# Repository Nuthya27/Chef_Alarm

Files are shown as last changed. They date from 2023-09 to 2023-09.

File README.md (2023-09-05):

# Chef_Alarm

My first individual project, Chef Alarm, the modern precision cooking equipment is made to take culinary experiences to new heights. This cutting-edge appliance guarantees that the meals are always cooked to perfection, whether you're a seasoned home cook or a professional chef. With its advanced technology and user-friendly design, the Chef Alarm is the ideal assistant for producing safe, delicious results in the kitchen.

   

## Features

  * On/Off switch with a red LED indicator.
  * Bluetooth connectivity to a mobile app.
  * Temperature sensor probe for meal temperature measurement.
  * Capacity to use two probes for monitoring two meals simultaneously.
  * Real-time temperature readings and cooking progress via the mobile app.
  * User-settable meal temperature via the app.
  * Notifications via the mobile app and the device's alarm buzzer when the desired temperature is reached.
  * Rechargeable with mini-USB charging and a green LED charging indicator.
  * Precise temperature monitoring for consistent cooking results.
  * Time and effort-saving cooking experience.

## Specifications

 * Minimum Temperature: -55 ºC
 * Maximum Temperature: 125 ºC
 * Temperature Accuracy: ±0.4℃ (at -10℃ ~ +85℃)
 * Battery Type: 3.7V Li-ion Battery
 * Battery Capacity: 1000mAh
 * Battery Life: 15 hours to 20 hours
 * Operating Voltage: 3.3 V
 * Current Range: 48 mA to 65 mA
 * Number of probes: 1
 * Probe Material: Stainless Steel
 * Probe Cable Length: 100 cm
 * Water-resistant 
 * Alarm sound: 90 dB
 * Bluetooth version: 4.2

## Functionality

Let's take a closer look at the inner workings of the Chef Alarm. The block diagram below illustrates how the various components of the circuit come together seamlessly to accomplish the tasks of this culinary companion.



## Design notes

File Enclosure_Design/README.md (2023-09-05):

# Enclosure Design

To house the prototype, I utilized SolidWorks software to design the enclosure, which was subsequently 3D printed and then assembled.



The enclosure, shown below, was designed using SolidWorks to enhance both its aesthetic appeal and ensure its moldability, representing another step forward in product development.



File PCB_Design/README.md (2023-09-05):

# PCB Design

## Schematic Design

### Voltage Regulating Circuit

This circuit input is connected to the 3.7V Li-ion battery via a switch. A low dropout linear regulator, 
LM1117 regulates the output voltage at 3.3V. The red LED is connected parallelly to the output side to 
indicate whether the power is on.



### Battery Charging Circuit

This charging circuit is used to charge the 3.7V Lithium-ion cell. The MCP73831 IC works as the Li ion charge management controller. The 5V input must be supplied via the mini-USB port. The green 
LED will turn off when the battery is fully charged indicating to unplug the charger.



### Main Circuit

ESP32- WROOM- 32D is the microcontroller used here since the integration of Bluetooth with the 
microcontroller IC helps with the Bluetooth mobile app connection without using an external Bluetooth 
module. There are two terminal blocks to connect two DS18B20 temperature sensor probes with a 
pulldown resistor. The buzzer is also connected to an I/O pin of the microcontroller.



### Programming Circuit

This part of the circuit is used to program the ESP32 microcontroller.



## PCB

### Bottom Layer



### Top Layer



### PCB after soldering



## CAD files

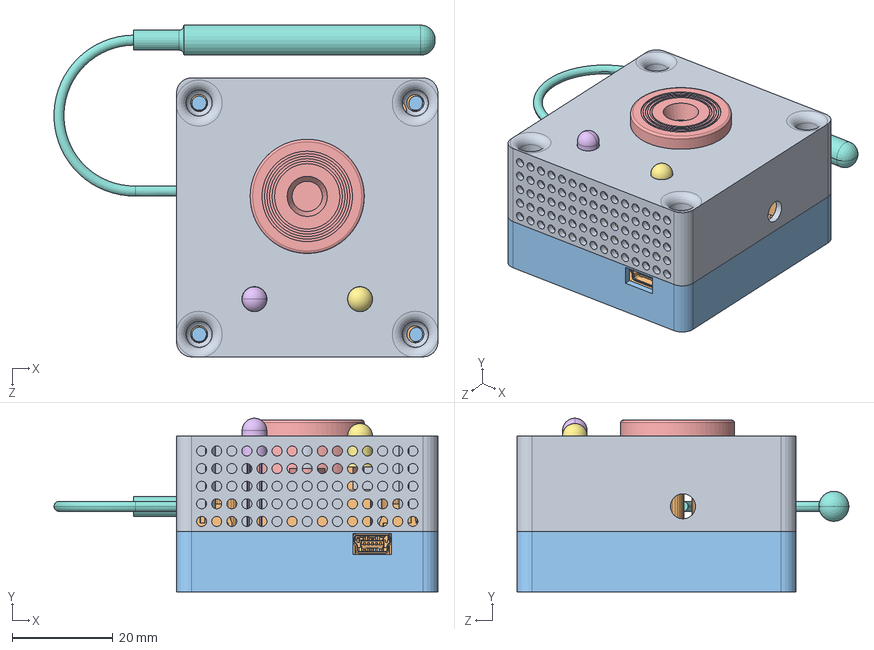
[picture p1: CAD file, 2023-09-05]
Enclosure_Design/Assemble/ChefAlarm.SLDASM
76.4 x 34.5 x 66.0 mm
Upper part
ChefAlarmPCB
lower part
li ion cell
Beeper buzzer 3-24V 23dia 11h leaded.step
LED green.step
red-led-5mm
ds18b20.step

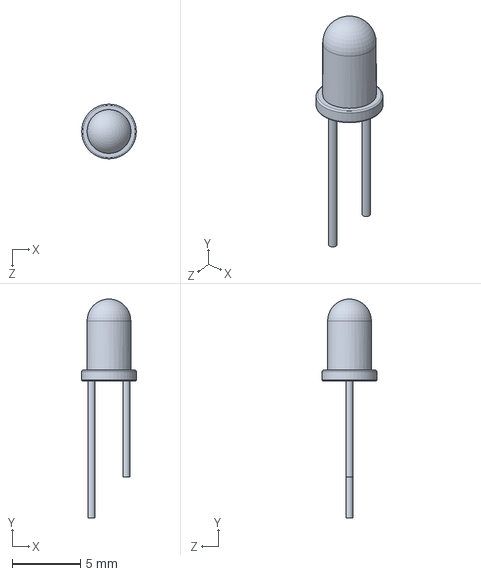
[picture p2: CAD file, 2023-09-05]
Enclosure_Design/Assemble/RED LED.SLDPRT
4.00 x 16.0 x 4.00 mm

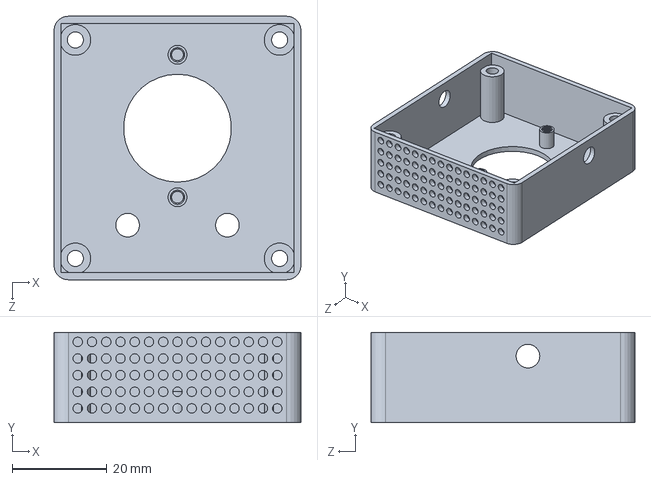
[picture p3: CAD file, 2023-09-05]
Enclosure_Design/Upper part.SLDPRT
52.0 x 19.0 x 55.5 mm

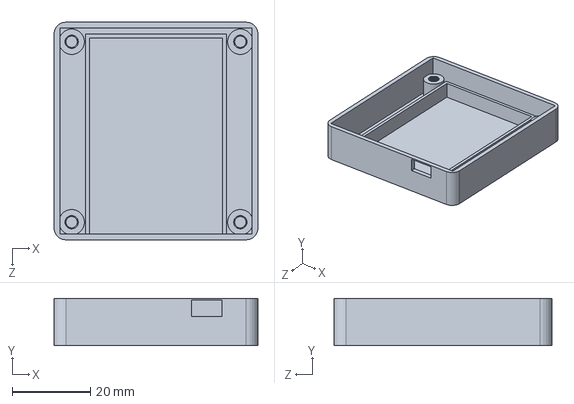
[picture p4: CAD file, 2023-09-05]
Enclosure_Design/Assemble/lower part.SLDPRT
52.0 x 12.0 x 55.5 mm

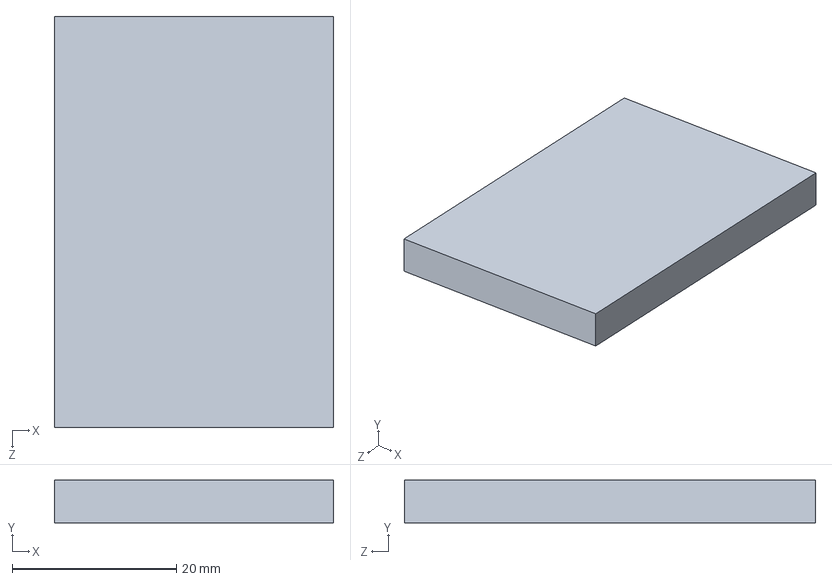
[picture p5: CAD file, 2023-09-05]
Enclosure_Design/Assemble/li ion cell.SLDPRT
34.0 x 5.20 x 50.0 mm

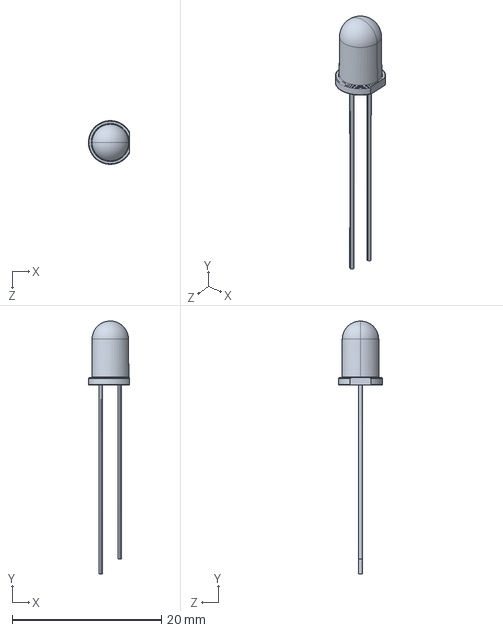
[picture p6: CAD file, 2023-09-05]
Enclosure_Design/Assemble/LED green.step.SLDPRT
5.52 x 33.9 x 5.86 mm

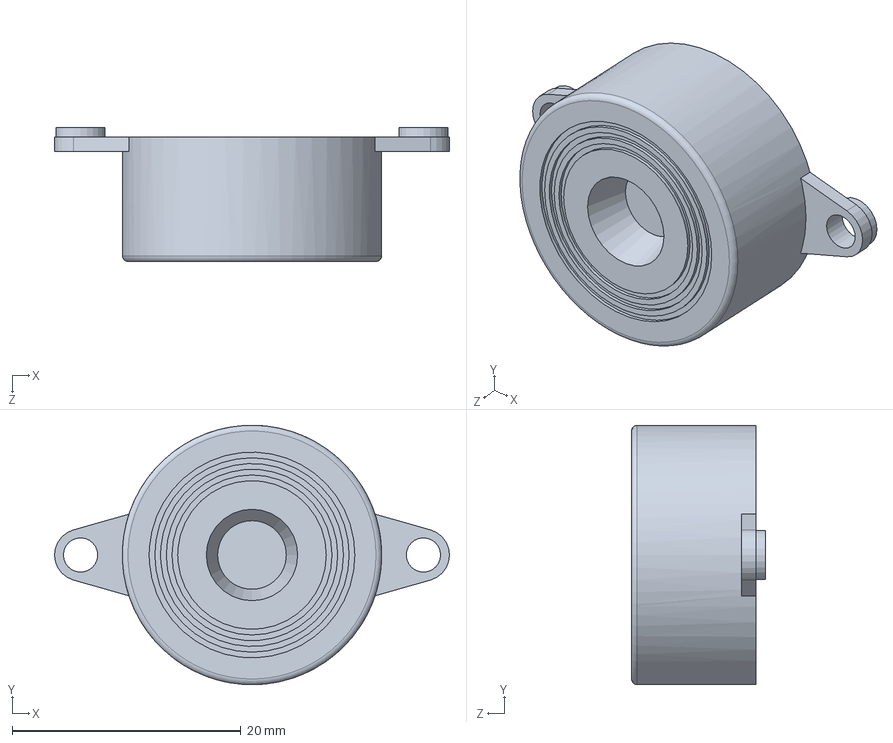
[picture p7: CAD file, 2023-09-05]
Enclosure_Design/Assemble/Beeper buzzer 3-24V 23dia 11h leaded.step.SLDPRT
34.6 x 22.7 x 11.7 mm

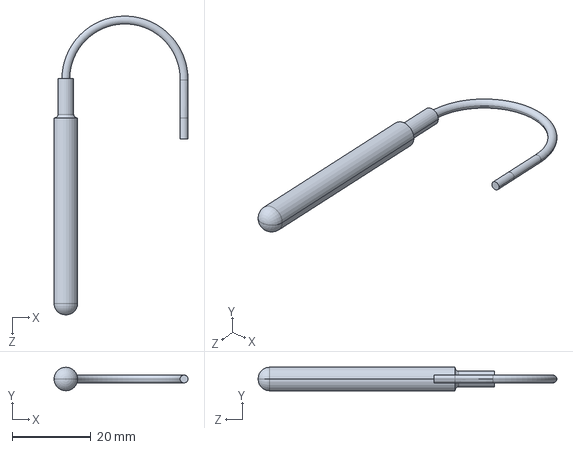
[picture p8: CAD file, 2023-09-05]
Enclosure_Design/Assemble/ds18b20.step.SLDPRT
34.0 x 6.00 x 75.8 mm

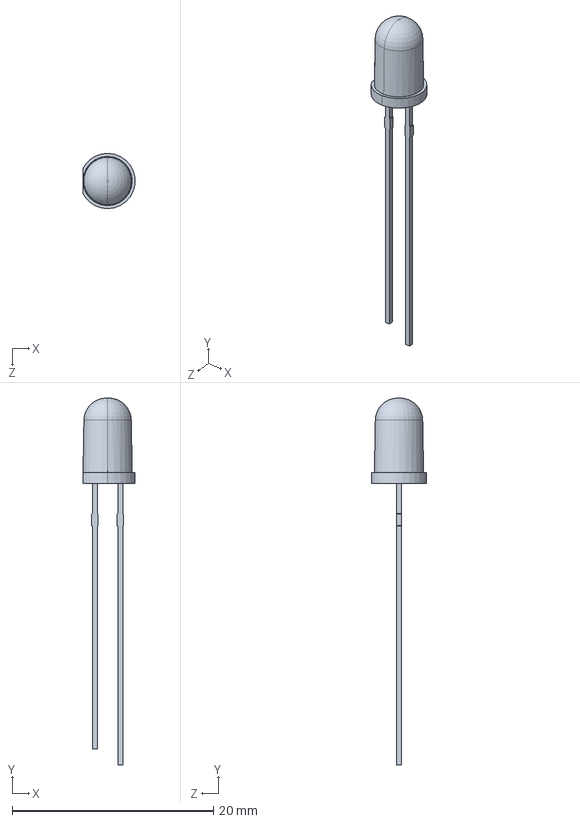
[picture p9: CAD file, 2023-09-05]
Enclosure_Design/Assemble/LED 5mm.step.SLDPRT
5.18 x 36.5 x 5.50 mm

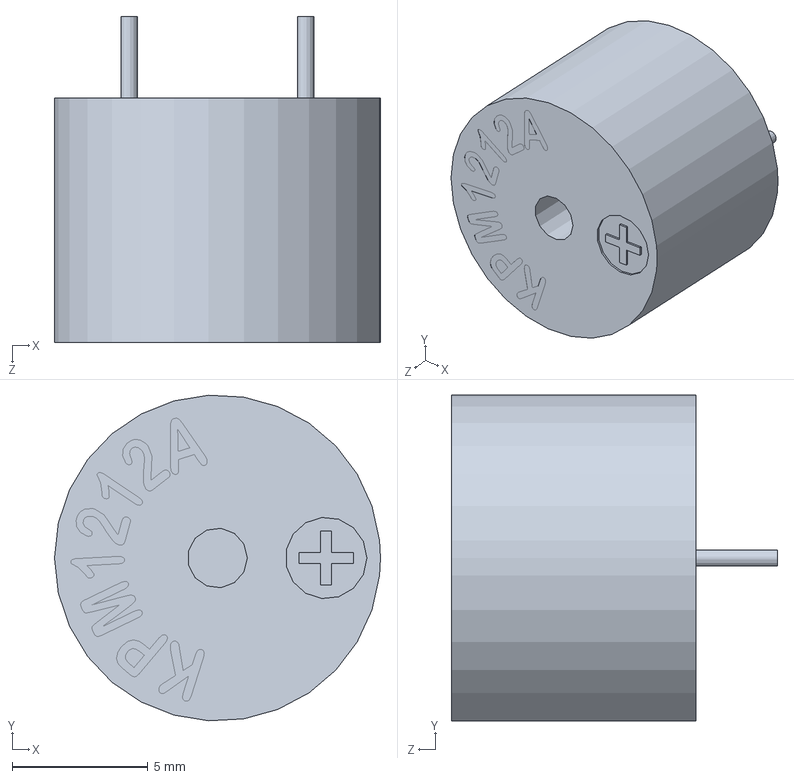
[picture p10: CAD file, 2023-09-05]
Enclosure_Design/Assemble/Buzze2.SLDPRT
12.0 x 12.0 x 12.0 mm

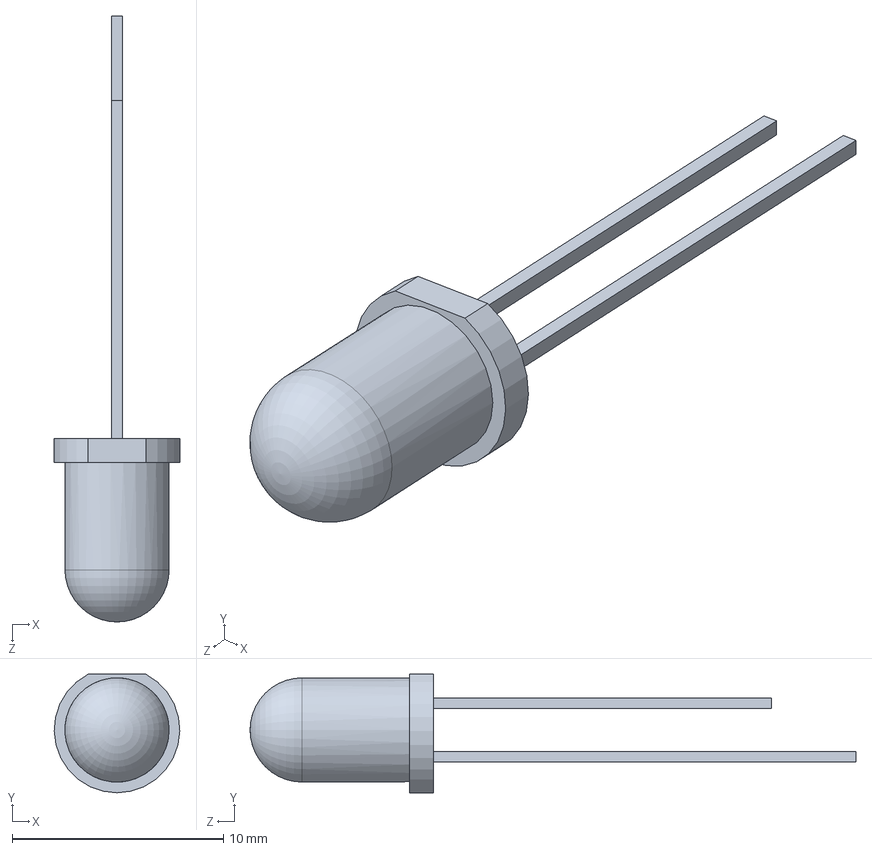
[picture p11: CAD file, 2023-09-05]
Enclosure_Design/Assemble/red-led-5mm.SLDPRT
5.95 x 5.62 x 28.7 mm

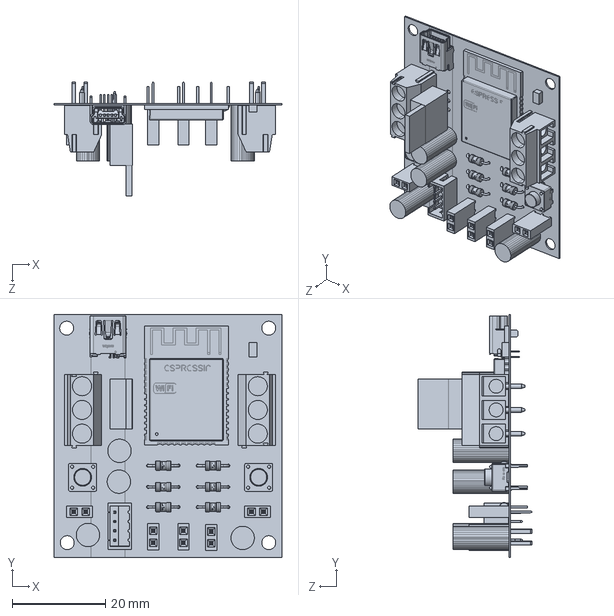
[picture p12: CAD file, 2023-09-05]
Enclosure_Design/Assemble/ChefAlarmPCB.SLDPRT
48.8 x 52.1 x 24.3 mm
